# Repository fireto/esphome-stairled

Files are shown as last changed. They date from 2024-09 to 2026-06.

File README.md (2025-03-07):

# esphome-stairled

esphome-stairled based on ESP Home with HomeAssistant integration via MQTT or native esphome API

It controls 16 PWM outputs via PCA9685 i2c LED controller
[datasheet](https://www.nxp.com/docs/en/data-sheet/PCA9685.pdf)

Optional Temperature and barometric pressure sensor: 
[BMP180](https://www.digikey.com/htmldatasheets/production/856385/0/0/1/BMP180-Datasheet.pdf)

in order to compile and deploy this project you need to get [esphome.io](https://esphome.io)

```podman run --rm -v "${PWD}":/config --device=/dev/ttyUSB0 -it esphome/esphome:latest run ./stairLed.yml```

BOM

* [1x Olimex ESP32POE](https://www.olimex.com/Products/IoT/ESP32/ESP32-POE/open-source-hardware)
* [1x Olimex UEXT CABLE-IDC10-15cm](https://www.olimex.com/Products/Modules/Adapters/CABLE-IDC10-15cm/)
* [1x PCA9685PW 16 Channel 12-bit PWM/Servo Driver-I2C interface](https://www.aliexpress.com/item/1005005973866782.html)
* [1x DC/DC BUCK 3A MP1584 adjustable buck module regulator LM2596S](https://www.aliexpress.com/item/32841466894.html)
* [1x BMP180 Digital Barometric Pressure Sensor](https://www.aliexpress.com/item/32709141948.html)
* [2x RJ45 PCB connector](https://vikiwat.com/product/19790/konektor-rj45-f-pcb.html)
* [5x4, 1x6, Female pin headers ]
* [2x10 Male pin headers]
* [Plastic DIN mounted box-P912036](https://eshop-bg.com/produkt/%d0%bf%d0%bb%d0%b0%d1%81%d1%82%d0%bc%d0%b0%d1%81%d0%be%d0%b2%d0%b0-%d0%ba%d1%83%d1%82%d0%b8%d1%8f-%d0%b7%d0%b0-din-%d1%88%d0%b8%d0%bd%d0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)
* [2x Panasonic PIR sensor](https://www.farnell.com/datasheets/2267095.pdf)

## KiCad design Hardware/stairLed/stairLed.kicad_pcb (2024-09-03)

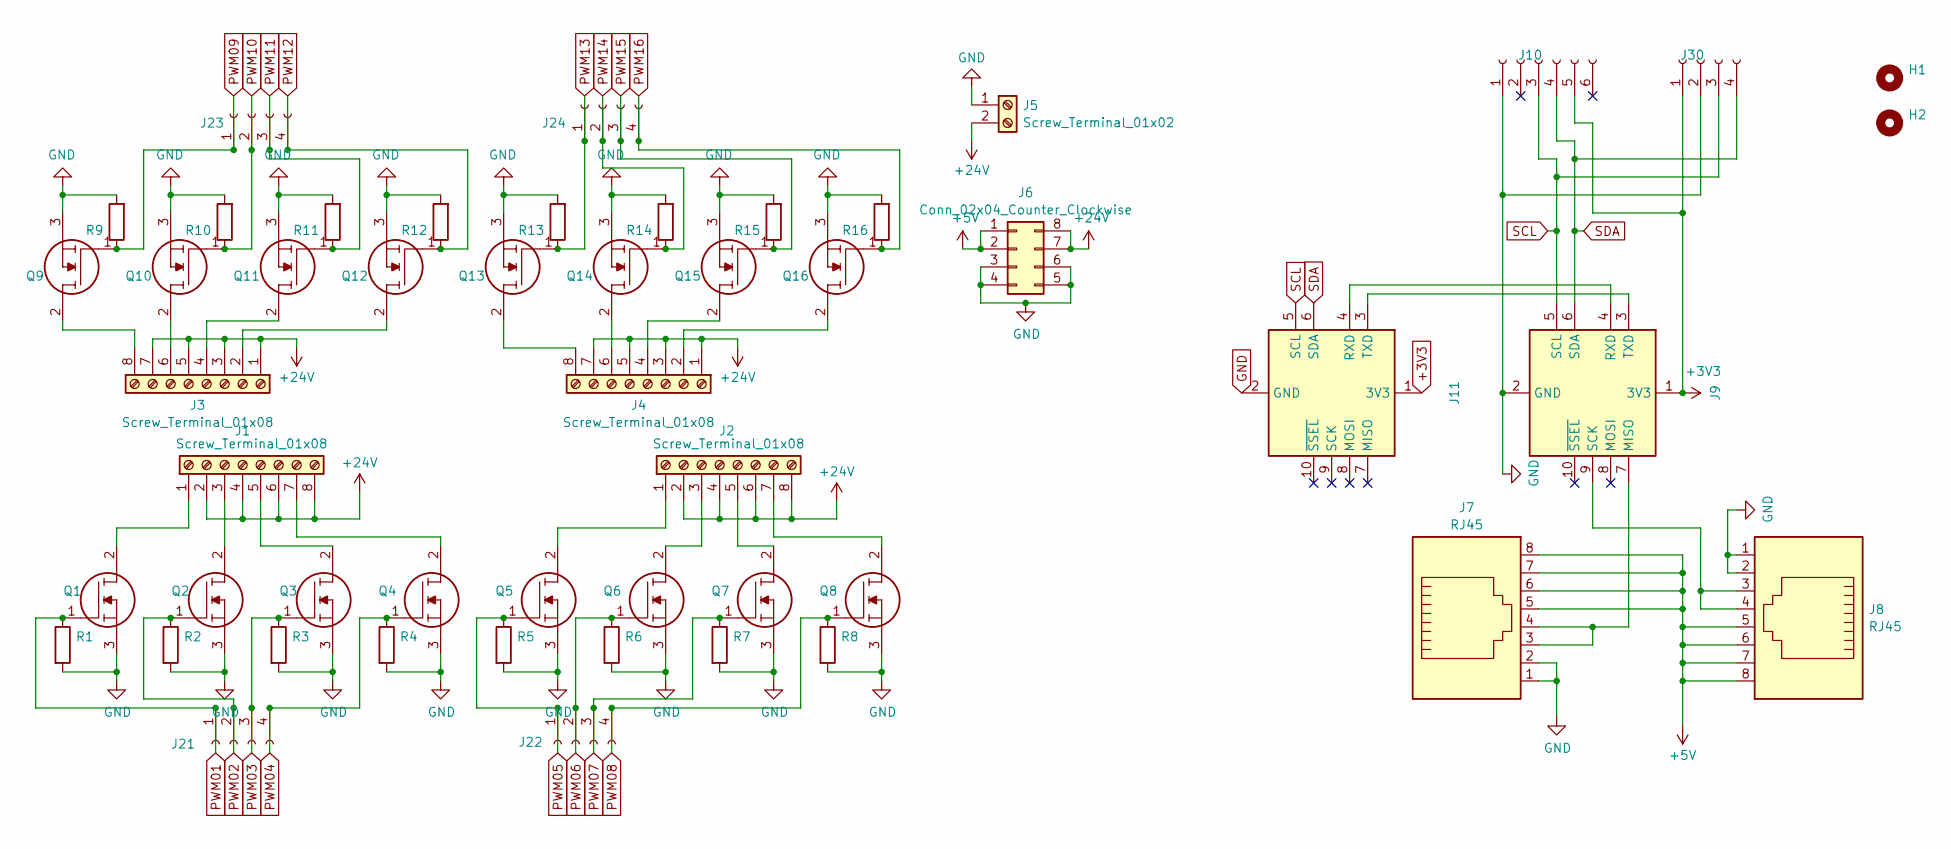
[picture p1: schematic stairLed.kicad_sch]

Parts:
H1, H2: MountingHole_3.2mm_M3
J1, J2, J3, J4: Screw_Terminal_01x08; TerminalBlock_bornier-8_P5.08mm
J5: Screw_Terminal_01x02; TerminalBlock_bornier-2_P5.08mm
J6: Conn_02x04_Counter_Clockwise; MP1584EN_dc-dc_module
J7, J8: RJ45; RJ45-vikvat-30757
J9, J11: PinSocket_2x05_P2.54mm_Vertical
J10: PinSocket_1x06_P2.54mm_Vertical
J21, J22, J23, J24, J30: PinSocket_1x04_P2.54mm_Vertical
Q1, Q2, Q3, Q4, Q5, Q6, Q7, Q8, Q9, Q10, Q11, Q12, Q13, Q14, Q15, Q16: FDD8447L; Manufacturer_Part_Number FDD8447L; Mouser Part Number 512-FDD8447L
R1, R2, R3, R4, R5, R6, R7, R8, R9, R10, R11, R12, R13, R14, R15, R16: R_0805_2012Metric

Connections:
+3V3: J9.1 (3V3), J10.5, J11.1 (3V3), J30.1
+5V: J6.1, J6.2, J7.5, J7.6, J7.7, J7.8, J8.5, J8.6, J8.7, J8.8
+24V: J1.2, J1.4, J1.6, J1.8, J2.2, J2.4, J2.6, J2.8, J3.1, J3.3, J3.5, J3.7, J4.1, J4.3, J4.5, J4.7, J5.2, J6.7, J6.8
GND: J5.1, J6.3, J6.4, J6.5, J6.6, J7.1, J7.2, J8.1, J8.2, J9.2 (GND), J10.1, J11.2 (GND), J30.2, Q1.3, Q2.3, Q3.3, Q4.3, Q5.3, Q6.3, Q7.3, Q8.3, Q9.3, Q10.3, Q11.3, Q12.3, Q13.3, Q14.3, Q15.3, Q16.3, R1.2, R2.2, R3.2, R4.2, R5.2, R6.2, R7.2, R8.2, R9.2, R10.2, R11.2, R12.2, R13.2, R14.2, R15.2, R16.2
unnamed: J1.1, Q1.2
unnamed: J1.3, Q2.2
unnamed: J1.5, Q3.2
unnamed: J1.7, Q4.2
unnamed: J2.1, Q5.2
unnamed: J2.3, Q6.2
unnamed: J2.5, Q7.2
unnamed: J2.7, Q8.2
unnamed: J3.2, Q12.2
unnamed: J3.4, Q11.2
unnamed: J3.6, Q10.2
unnamed: J3.8, Q9.2
unnamed: J4.2, Q16.2
unnamed: J4.4, Q15.2
unnamed: J4.6, Q14.2
unnamed: J4.8, Q13.2
unnamed: J7.3, J7.4, J9.7 (MISO)
unnamed: J8.3, J8.4, J9.9 (SCK)
unnamed: J9.4 (RXD), J11.4 (RXD)
unnamed: J9.3 (TXD), J11.3 (TXD)
PWM01: J21.1, Q1.1, R1.1
PWM02: J21.2, Q2.1, R2.1
PWM03: J21.3, Q3.1, R3.1
PWM04: J21.4, Q4.1, R4.1
PWM05: J22.1, Q5.1, R5.1
PWM06: J22.2, Q6.1, R6.1
PWM07: J22.3, Q7.1, R7.1
PWM08: J22.4, Q8.1, R8.1
PWM09: J23.1, Q9.1, R9.1
PWM10: J23.2, Q10.1, R10.1
PWM11: J23.3, Q11.1, R11.1
PWM12: J23.4, Q12.1, R12.1
PWM13: J24.1, Q13.1, R13.1
PWM14: J24.2, Q14.1, R14.1
PWM15: J24.3, Q15.1, R15.1
PWM16: J24.4, Q16.1, R16.1
SCL: J9.5 (SCL), J10.3, J11.5 (SCL), J30.3
SDA: J9.6 (SDA), J10.4, J11.6 (SDA), J30.4

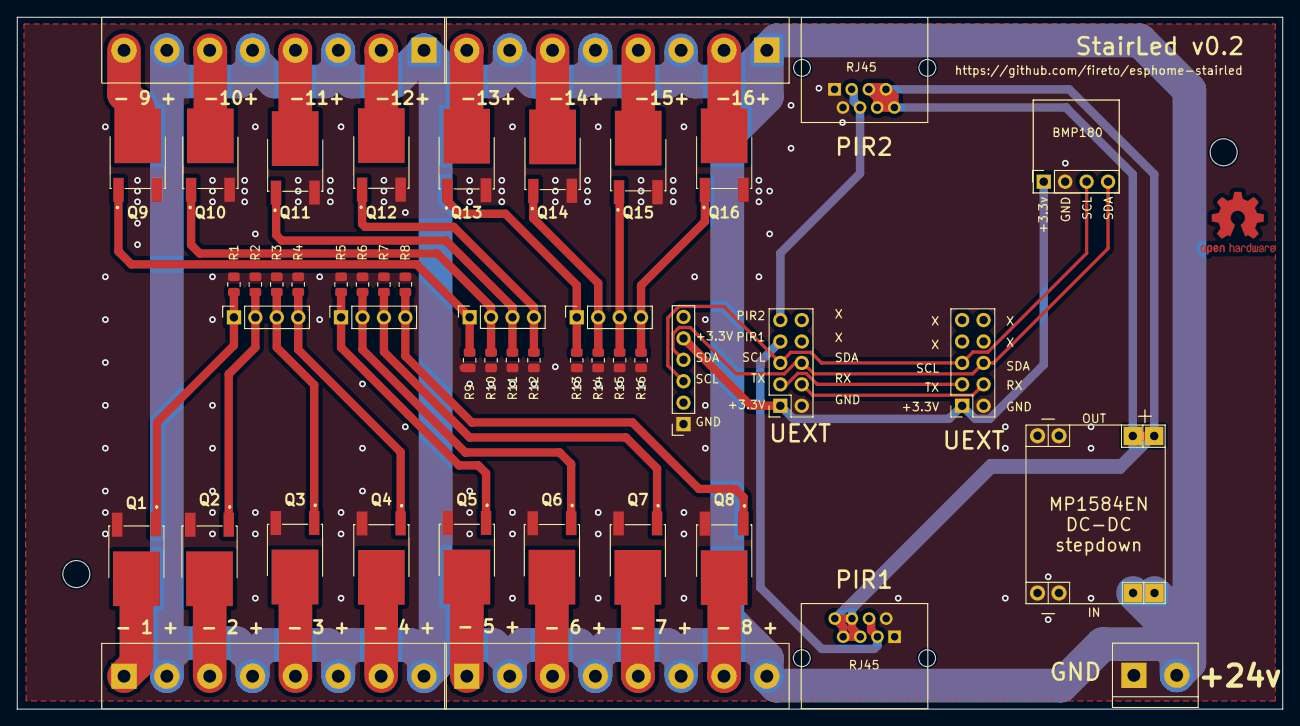
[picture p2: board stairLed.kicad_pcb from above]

Board: 2 copper layers, 150.0 x 82.0 mm, 50 parts (0 on the bottom side), 42 nets.

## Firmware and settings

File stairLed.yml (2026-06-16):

### stairLedLight main
substitutions:
  devicename: stairledlight
  upperDevicename: stair Led Light
  maxBright: "70"       # maximum brightness for the leds to reach (in %)
  nightBright: "25"     # brightness for always-on during night
  transLenghtOn: "1.5"  # time for transition from Off to On
  delayLenghtOn: "0.2" # delay between turining on the next step
  transLenghtOff: "4"   # time for tranistion from On to Off
  delayLenghtOff: "0.5" # delay between turning off the next step
  stayOn: "256"        # duration of time the lights stay on after all lights are turned on
  nightTransLength: "40" # transition length for fading to night brightness

esphome:
  name: $devicename
  on_boot:
    - priority: 1000
      then:
        - logger.set_level: WARN

esp32:
  board: esp32-poe
  framework:
    type: esp-idf
    # version: latest
    advanced:
      minimum_chip_revision: "3.0"

packages:
  # wifi: !include common/wifi.yml
  ethernet: !include common/ethernet.yml
  api: !include common/api.yml
  ota: !include common/ota.yml
  # mqtt: !include common/mqtt.yml
  logger: !include common/logger.yml
  sun: !include common/sun.yml
  time: !include common/time.yml
  web_server: !include common/webserver.yml

external_components:
  - source: github://muxa/esphome-state-machine@main
    components: [state_machine]

# Act as a Home Assistant Bluetooth proxy (BLE scanning + proxied connections).
# Runs alongside Ethernet; adds notable flash/RAM use from the BLE stack.
esp32_ble_tracker:
  scan_parameters:
    interval: 1100ms
    window: 1100ms
    active: true

bluetooth_proxy:
  active: true

i2c:
  scan: True

# load module for PCA9685 16-Channel 12-bit PWM/Servo Driver I2C
# datasheet https://www.nxp.com/docs/en/data-sheet/PCA9685.pdf
pca9685:
  - frequency: 1000
    # Default "linear" phase-staggers each channel's PWM start, which makes the
    # high-numbered channels' pulses wrap past the cycle reset. Rewriting those
    # wrapped pulses mid-cycle (the driver rewrites all channels on every change)
    # glitches the steady steps -> steps 1-5 (channels 11-15) flicker during fades.
    # "none" starts every channel at phase 0 so no pulse wraps. Tradeoff: all
    # channels rise together -> slightly higher per-cycle inrush current.
    phase_balancer: none

#Define PCA9685 PWM chnnels and register them as outputs in ESPHome
# pins 0-15 are defined as channel 0-15
output:
  - platform: pca9685
    id: pca1_0
    channel: 15
    inverted: False

  - platform: pca9685
    id: pca1_1
    channel: 14
    inverted: False

  - platform: pca9685
    id: pca1_2
    channel: 13
    inverted: False

  - platform: pca9685
    id: pca1_3
    channel: 12
    inverted: False

  - platform: pca9685
    id: pca1_4
    channel: 11
    inverted: False

  - platform: pca9685
    id: pca1_5
    channel: 10
    inverted: False

  - platform: pca9685
    id: pca1_6
    channel: 9
    inverted: False

  - platform: pca9685
    id: pca1_7
    channel: 8
    inverted: False

  - platform: pca9685
    id: pca1_8
    channel: 7
    inverted: False

  - platform: pca9685
    id: pca1_9
    channel: 6
    inverted: False

  - platform: pca9685
    id: pca1_10
    channel: 5
    inverted: False

  - platform: pca9685
    id: pca1_11
    channel: 4
    inverted: False

  - platform: pca9685
    id: pca1_12
    channel: 3
    inverted: False

  - platform: pca9685
    id: pca1_13
    channel: 2
    inverted: False

  - platform: pca9685
    id: pca1_14
    channel: 1
    inverted: False

  - platform: pca9685
    id: pca1_15
    channel: 0
    inverted: False
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

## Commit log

2024-09-03 adding KiCad hardware files
    [stairLed.kicad_pcb, stairLed.kicad_sch]
2024-09-03 fixing common configuration, renaming main yaml file
    [stairLed.yml]
2025-03-07 update .gitignore and README for improved documentation and ignore patterns; fix YAML configuration for ESP32
    [stairLed.yml]
2025-04-11 switch webserver to v3
2026-04-24 fix bugs and refactor stair LED scripts
    - fix chip revision warning (minimum_chip_revision: 3.0)
    - fix nightTransLength substitution replacing incorrect transition_length values
    - fix double step16 turn-off in fadeOffBottomTop
    - fix missing delay after step16 in fadeOffTopBottom
    - fix fade-on/fade-off race in state machine on_leave (stop fadeOn before starting fadeOff)
    - nightMode: run fadeOffBottomTop to clear intermediate steps, then reset state machine via idleTimeout
    - collapse fadeOnOffBottomTop/TopBottom to delegate to sub-scripts
    - extract stopAll script; simplify stopAllScripts button and halloween fade-off
    - tune: nightBright 30→25, delayLenghtOn 0.25→0.2, tran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
    [stairLed.yml]
2026-06-12 Exposed Internal EPS32 temperature
2026-06-15 Ceiling as step 17: delay on-event to last step max + emit off-events
    Delay the ascended/descended events by one ON transition so the ceiling
    lights fire only after the last LED step reaches max (not mid-fade). Add
    ascended_off/descended_off events at the end of each OFF animation so HA
    can fade the ceiling out as the final step instead of on a 5-min timer.
2026-06-16 Fix step 1-5 flicker, off/on fade race, and PIR delayed_off
    - pca9685: set phase_balancer to none so high-channel PWM pulses no
    longer wrap past the cycle reset; eliminates steps 1-5 flickering when
    other steps fade.
    - state_machine: run stopAll on entering occupiedBottom/occupiedTop so a
    still-draining off-fade can't run concurrently with the new on-fade.
    - binary_sensor: reduce both PIR delayed_off filters from 10s to 2s.
    [stairLed.yml]
2026-06-16 Move device domain to secrets; drop identifying wifi comments
    - Replace hardcoded $domainName substitution with !secret domainName on
    both the ethernet and wifi domain options.
    - Remove commented-out alternate wifi SSIDs that named a location/person.
    [stairLed.yml]
